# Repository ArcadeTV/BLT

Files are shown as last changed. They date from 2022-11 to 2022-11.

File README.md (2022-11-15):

## BLT (Button Layout Toggler)
### v20221101
#### ArcadeTV

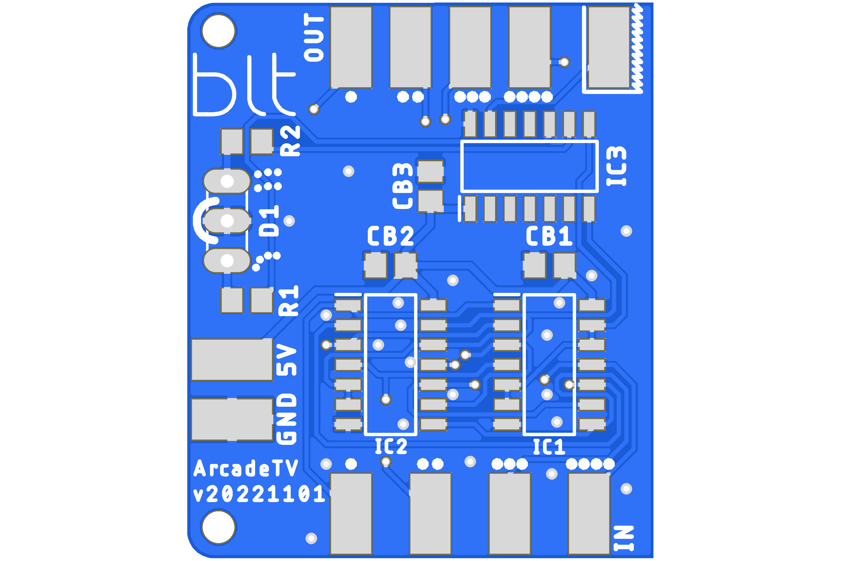
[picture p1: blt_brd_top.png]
BLT pcb


| Part | Value | Device | Package |
| ---- | --- | --- | --- |
| CB1  | 100nF | C-USC0805 | C0805 |
| CB2  | 100nF | C-USC0805 | C0805 |
| CB3  | 100nF | C-USC0805 | C0805 |
| D1 | | DUOLED2X5 | DUOLED2X5 |
| IC1  | 74HC4066D | 74HC4066D | SOIC127P600X175-14N |
| IC2  | 74HC4066D | 74HC4066D | SOIC127P600X175-14N |
| IC3  | ATTINY84V-10SSUR | ATTINY84V-10SSUR | SOIC127P600X175-14N |
| R1 | 220 | R-US_R0805 | R0805 |
| R2 | 220 | R-US_R0805 | R0805 |

---

#### Description:
This pcb remaps 4 buttons of a common-ground controller to two different layouts,
given that your controller has a 6-button-layout.
I was tired of having to reconfigure my arcade stick every time I switched games between
Street Fighter (6 Buttons) and Neo Geo (4 Buttons), so I came up with a solution that 
goes between the first four input signal lines from either a supergun or jamma harness.
The toggler pad on the pcb goes to a switch that connects to GND. This will trigger
the switching process and visual feedback can be added by an optional 2-color-LED.
Buttons 5 and 6 are not involved.

#### Microcontroller:
Please mind that the ATtiny84 microcontroller needs to be programmed
with the provided hex file.

#### PCB
Use the provided gerber files from the [releases tab](https://github.com/ArcadeTV/BLT/releases/latest) to order your pcb from your favorite manufacturer.

Eagle source files for editing also exist in this repository.

#### Installation
Populate the pcb after programming the ATtiny microcontroller.
Connect the lines coming from your supergun or jamma harness to the pads
marked with IN. Connect the button-lines to the pads marked OUT.
Connect a switch to the toggler-pad on the upper right of the pcb that
connects temporary to GND upon being pressed.
Install a 2-color-LED as you see fit. (Adjust R1 and R2 according to your LED specs)

```
Layout #1 (Street Fighter Style):
   .-.   .-.   .-.
  ( 1 ) ( 2 ) ( 3 )
   '-'   '-'   '-'
 .-.   .-.   .-.
( 4 ) ( 5 ) ( 6 )
 '-'   '-'   '-'

Layout #2 (Neo Geo Style):
   .-.   .-.   .-.
  ( 2 ) ( 3 ) ( 4 )
   '-'   '-'   '-'
 .-.   .-.   .-.
( 1 ) ( 5 ) ( 6 )
 '-'   '-'   '-'

```

Tested on a HORI Fighting Stick V3 (PS3 Version) that was rewired with a DB15 cable and connector
for use with a MINIGUN v2.5. The PS button on that stick was wired for toggling.

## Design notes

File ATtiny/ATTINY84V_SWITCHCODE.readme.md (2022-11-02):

### SWITCHCODE for ATtiny84
#### v20221101
##### ArcadeTV

```
                _____
       VCC  01-|°    |-14 GND
            02-|     |-13 BUTTON  (0)
            03-|     |-12 RESET   (1)
            04-|     |-11 !RESET  (2)
            05-|     |-10 LED-R   (3)
            06-|     |-09 LED-G   (4)
!TOGGLE (6) 07-|_____|-08 TOGGLE  (5)

low:   0xE2
high:  0xD7
ext.:  0xFF
lock:  0xFF
```

-------------------------------------

### Description:

This mcu code toggles 2 pins high or low upon a button-press.
Feedback is given by 2 LED lines for 2 different colors and activation-blink-effect.
Also a 150ms reset signal is sent upon toggling from separate pins for either active-low or active-high systems.
The last state is saved to eprom and restored on power cycling.

### Compiling

Compile with Arduino IDE (select ATtinyCore as board) or your favorite AVR toolkit.

-------------------------------------

| PIN | Function |
| --- | --- |
| BUTTON  | Connect a switch to GND. No external pull-up or hardware-debounce needed. |
| RESET | Send a reset signal for 150ms to an active-high system. |
| !RESET  | Send a reset signal for 150ms to an active-low system. |
| LED-R | Connect a red LED pin with common-cathode via an appropriate resistor. |
| LED-G | Connect a green LED pin with common-cathode via an appropriate resistor. |
| TOGGLE  | Is set either HIGH or LOW depending on which state is active. |
| !TOGGLE | Is set either LOW or HIGH depending on which state is active. |

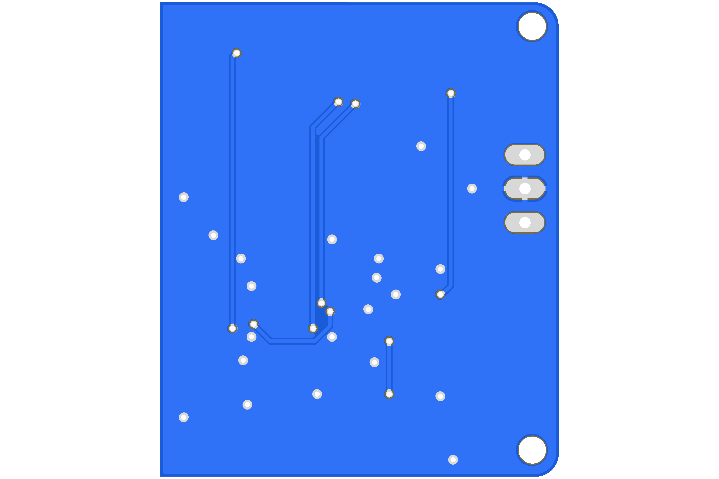
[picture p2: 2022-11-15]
blt_brd_btm.png

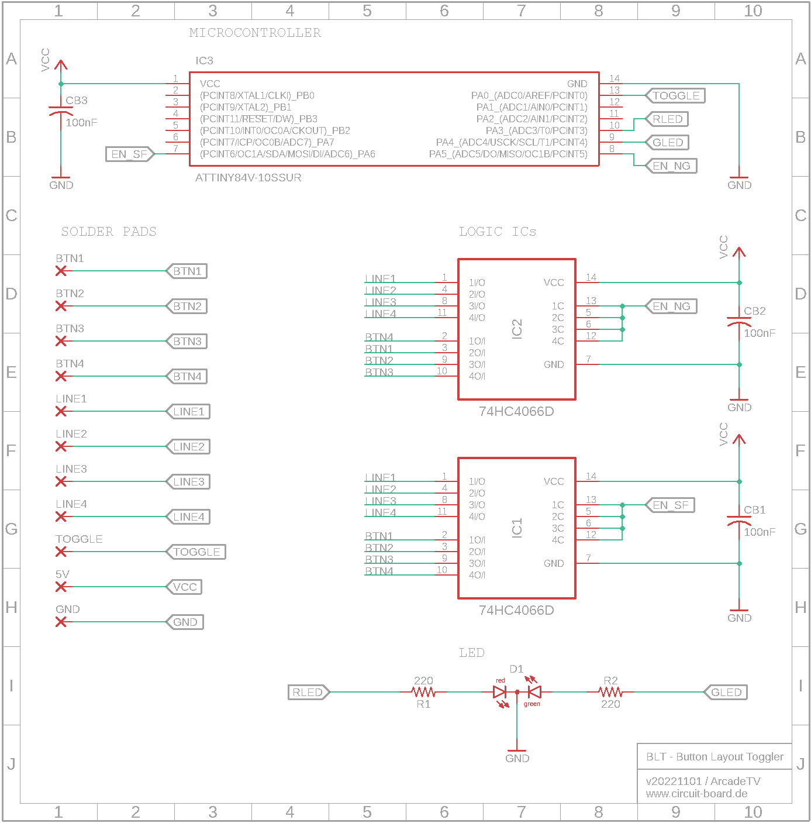
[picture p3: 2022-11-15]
blt_sch.png

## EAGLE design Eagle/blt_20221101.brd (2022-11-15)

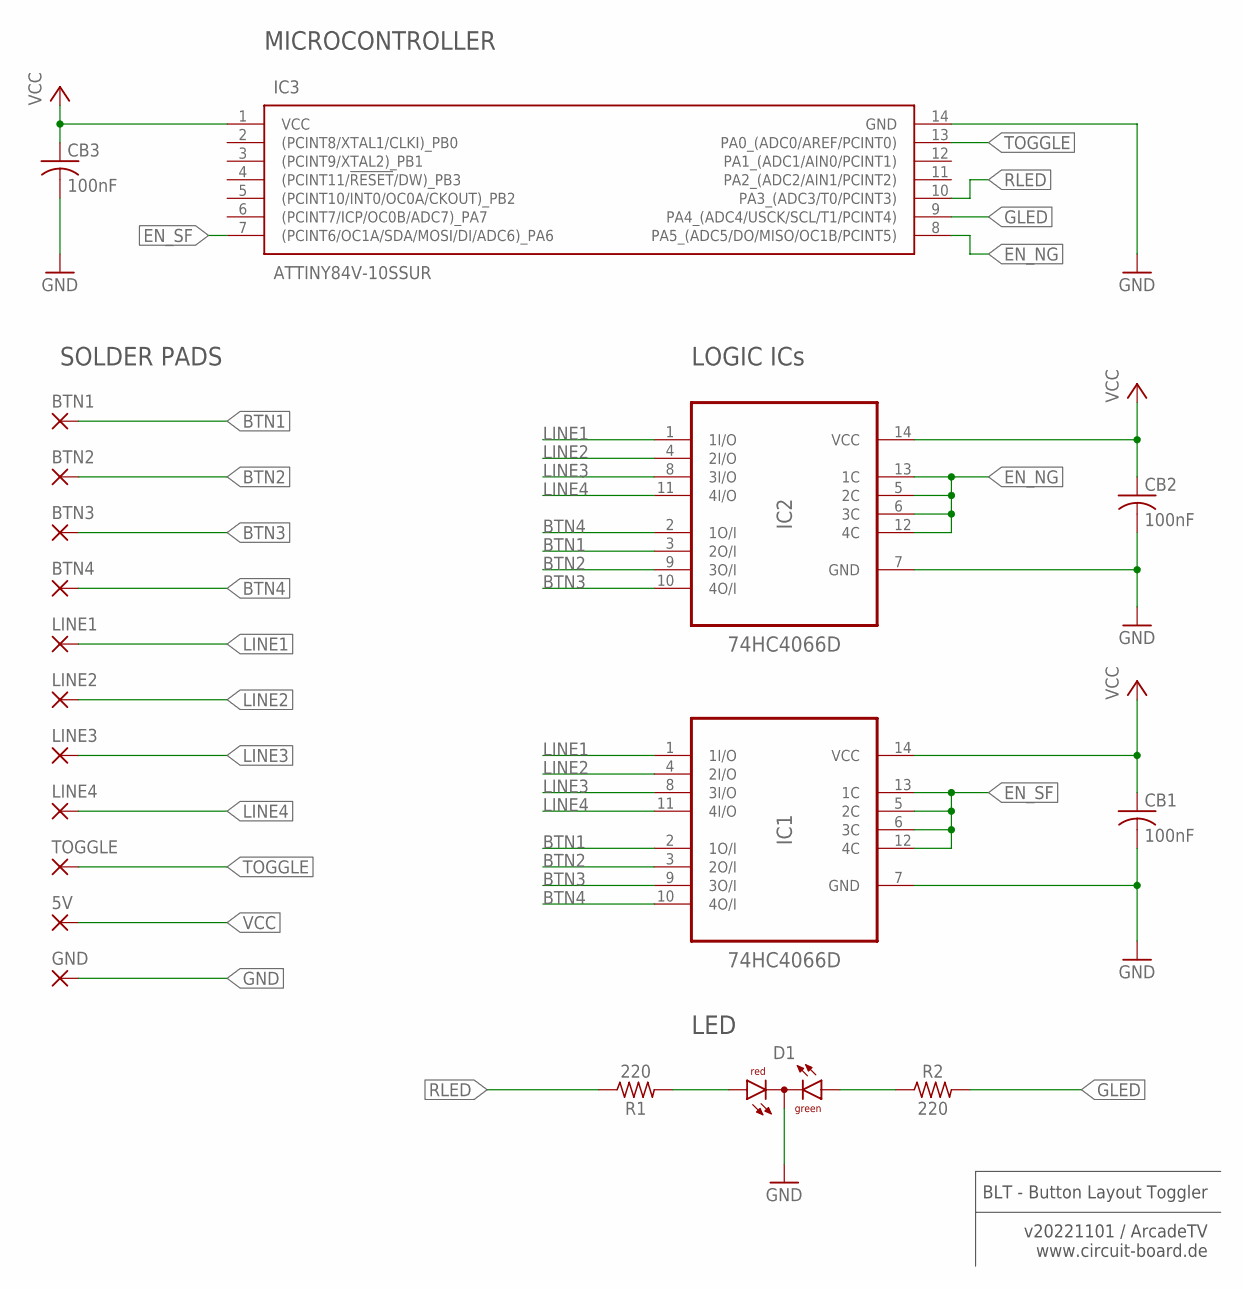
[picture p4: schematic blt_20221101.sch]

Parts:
5V: WIREPADSMD2,54-5,08; SMD2,54-5,08
BTN1, BTN2, BTN3, BTN4: WIREPADSMD2,54-5,08; SMD2,54-5,08
CB1, CB2, CB3: 100nF; C0805
D1: DUOLED2X5
GND: WIREPADSMD2,54-5,08; SMD2,54-5,08
IC1, IC2: 74HC4066D; SOIC127P600X175-14N
IC3: ATTINY84V-10SSUR; SOIC127P600X175-14N
LINE1, LINE2, LINE3, LINE4: WIREPADSMD2,54-5,08; SMD2,54-5,08
R1, R2: 220; R0805
TOGGLE: WIREPADSMD2,54-5,08; SMD2,54-5,08

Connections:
BTN1: BTN1.1, IC1.2 (1O/I), IC2.3 (2O/I)
BTN2: BTN2.1, IC1.3 (2O/I), IC2.9 (3O/I)
BTN3: BTN3.1, IC1.9 (3O/I), IC2.10 (4O/I)
BTN4: BTN4.1, IC1.10 (4O/I), IC2.2 (1O/I)
EN_NG: IC2.5 (2C), IC2.6 (3C), IC2.12 (4C), IC2.13 (1C), IC3.8 (PA5_(ADC5/DO/MISO/OC1B/PCINT5))
EN_SF: IC1.5 (2C), IC1.6 (3C), IC1.12 (4C), IC1.13 (1C), IC3.7 ((PCINT6/OC1A/SDA/MOSI/DI/ADC6)_PA6)
GLED: IC3.9 (PA4_(ADC4/USCK/SCL/T1/PCINT4)), R2.2
GND: CB1.2, CB2.2, CB3.2, D1.K (C), GND.1, IC1.7 (GND), IC2.7 (GND), IC3.14 (GND)
LINE1: IC1.1 (1I/O), IC2.1 (1I/O), LINE1.1
LINE2: IC1.4 (2I/O), IC2.4 (2I/O), LINE2.1
LINE3: IC1.8 (3I/O), IC2.8 (3I/O), LINE3.1
LINE4: IC1.11 (4I/O), IC2.11 (4I/O), LINE4.1
unnamed: D1.AR, R1.2
unnamed: D1.AG, R2.1
RLED: IC3.10 (PA3_(ADC3/T0/PCINT3)), R1.1
TOGGLE: IC3.13 (PA0_(ADC0/AREF/PCINT0)), TOGGLE.1
VCC: 5V.1, CB1.1, CB2.1, CB3.1, IC1.14 (VCC), IC2.14 (VCC), IC3.1 (VCC)

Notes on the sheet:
BLT - Button Layout Toggler v20221101 / ArcadeTV www.circuit-board.de
MICROCONTROLLER
SOLDER PADS
LOGIC ICs
LED

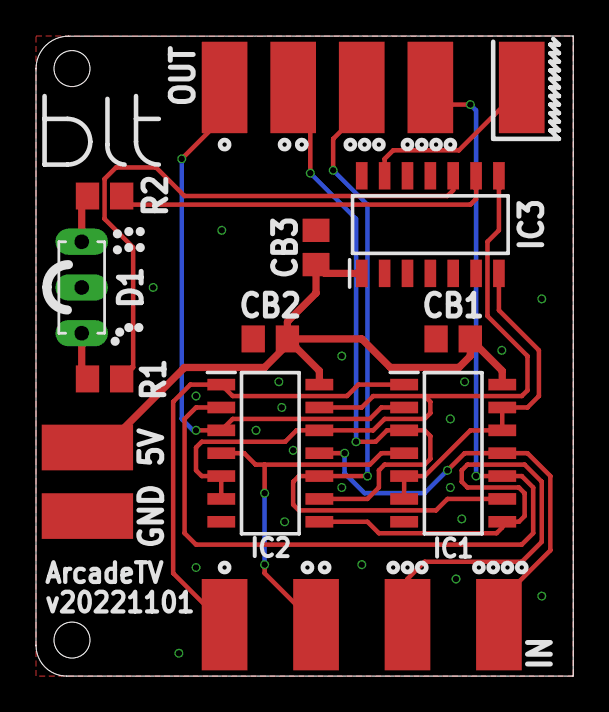
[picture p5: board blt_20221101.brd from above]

Board: 2 copper layers, 29.8 x 35.6 mm, 20 parts (0 on the bottom side), 17 nets.

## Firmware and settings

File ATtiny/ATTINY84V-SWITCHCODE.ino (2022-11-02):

#include <EEPROM.h>

const int buttonPin = 0;
const int ResetPin = 1;
const int invResetPin = 2;
const int RledPin = 3;
const int GledPin = 4;
const int TogglerPin = 5;
const int invTogglerPin = 6;

int GledState;
int RledState;
int resetState = HIGH;
int TogglerState;
int buttonState;
int lastButtonState = HIGH;

int eeprom_test;
int eeprom_value;
int eeprom_location;

unsigned long lastDebounceTime = 0;
unsigned long debounceDelay = 50;

int Count = 0;

void setup() {
  pinMode(buttonPin, INPUT);
  digitalWrite(buttonPin, HIGH);  // enable internal pullup

  pinMode(ResetPin, INPUT);
  digitalWrite(ResetPin, LOW);
  pinMode(invResetPin, INPUT);

  pinMode(TogglerPin, OUTPUT);
  pinMode(invTogglerPin, OUTPUT);

  pinMode(RledPin, OUTPUT);
  pinMode(GledPin, OUTPUT);

  eeprom_test = EEPROM.read(0);
  if (eeprom_test < 1) {
    EEPROM.write(0, 1);
    TogglerState = HIGH;
  } else if (eeprom_test == 1) {
    TogglerState = HIGH;
  } else if (eeprom_test == 2) {
    TogglerState = LOW;
  }

  digitalWrite(TogglerPin, TogglerState);
  digitalWrite(invTogglerPin, !TogglerState);

  if (TogglerState == LOW) {
    blinkGreen();
  } else {
    blinkRed();
  }
}

void setStates() {
  digitalWrite(TogglerPin, TogglerState);
  digitalWrite(invTogglerPin, !TogglerState);
  sendReset();
}

void sendReset() {
  // send reset for active-high
  PORTA |= (1 << ResetPin);
  DDRA |= (1 << ResetPin);
  // send reset for active-low
  pinMode(invResetPin, OUTPUT);
  delay(150);
  cancelReset();
}

void cancelReset() {
  // cancel reset for active-high
  DDRA &= ~(1 << ResetPin);
  PORTA &= ~(1 << ResetPin);
  // cancel reset for active-low
  pinMode(invResetPin, INPUT);
}

void toggleNow() {
  TogglerState = !TogglerState;
  setStates();
  digitalWrite(GledPin, LOW);
  digitalWrite(RledPin, LOW);
  if (TogglerState == LOW) {
    EEPROM.write(0, 2);
    blinkGreen();
  } else {
    EEPROM.write(0, 1);
    blinkRed();
  }
}

void blinkRed() {
  int Count = 0;
  while (Count <= 10) {
    delay((50 - ((Count * 10) / 2)) + 10);
    digitalWrite(RledPin, LOW);
    delay((50 - ((Count * 10) / 2)) + 10);
    digitalWrite(RledPin, HIGH);
    Count++;
  }
}

void blinkGreen() {
  int Count = 0;
  while (Count <= 10) {
    delay((50 - ((Count * 10) / 2)) + 10);
    digitalWrite(GledPin, LOW);
    delay((50 - ((Count * 10) / 2)) + 10);
    digitalWrite(GledPin, HIGH);
    Count++;
  }
}

void loop() {
  int reading = digitalRead(buttonPin);
  if (reading != lastButtonState) {
    lastDebounceTime = millis();
  }

  if ((millis() - lastDebounceTime) > debounceDelay) {
    if (reading != buttonState) {
      buttonState = reading;
      if (buttonState == LOW) {
        toggleNow();
      }
    }
  }
  lastButtonState = reading;
}
